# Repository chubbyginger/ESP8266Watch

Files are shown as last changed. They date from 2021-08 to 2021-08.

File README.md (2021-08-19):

# ESP8266Watch
ESP8266 WiFi模组自制可穿戴智能手表

## 功能
1. 使用内置DS1302时钟芯片提供RTC时钟。
2. 鉴于DS1302芯片准确性不高，也可连接WiFi后通过NTP时钟服务器同步时间。
3. 可以使用计时器、定时器等功能。
4. 访问本地文件系统文件或者连接服务器，阅读文本内容。
5. 具有可拓展性（往上面加点简单游戏什么的完全可以）。

## 版本

这个手表有两个版本：

1. dev版本：这个版本用的是一个电位器加一个按钮来操作手表。但是这个设计不方便放进手表，体积会特别大，是明显不合适的。因为不考虑用这个版本做成品，因此此版本没有PCB。

2. 正式版本：这个版本用三个按钮操作手表（上，下，确定），更方便放进手表。这个版本有PCB。

   另外，这个版本取消了DS1302的备用电池，因为其体积实在太大且没什么实际用处。DS1302的布局从SOIC改成了DIP，主要是因为我手残不会焊SOIC。电阻也改成直插式了。
## 制作说明
可以直接用Arduino编译程序下载（如果用ESP8266裸板需要另买USB转串口线一根，把里面TXD和RXD插到裸板的RXD和TXD上），也可以下载已经编译好的bin文件（现在还没准备好）。但是如果需要修改Flash片内内容，则必须用Arduino手动编译。

## 修改片内Flash方法
1. 先参考libconfig文件夹中安装依赖库的说明，安装库和文件系统工具。
2. 在源代码的data文件夹下放置需要的文件。
3. 找到工具->ESP8266 Sketch Data Upload，点击即可上传。

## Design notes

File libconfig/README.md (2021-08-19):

# 配置库
如果家里网不好，直接安装esp8266是巨慢的甚至可能根本装不上，可以用以下方法安装：

1. 从[这里](https://github.com/yangshunhuai/ESP8266Watch/releases/libconfig)下载库配置包
2. 解压缩
3. 运行config.bat
4. 在Arduino的首选项中有一个附加开发板管理器网址，把`https://arduino.esp8266.com/stable/package_esp8266com_index.json`填进去。
5. 在Arduino工具->开发板->开发板管理器中搜索esp8266，点进去，有一个选择版本的下拉菜单，进去选择3.0.2，点右边安装，因为有了预先下载的缓存，安装非常快。

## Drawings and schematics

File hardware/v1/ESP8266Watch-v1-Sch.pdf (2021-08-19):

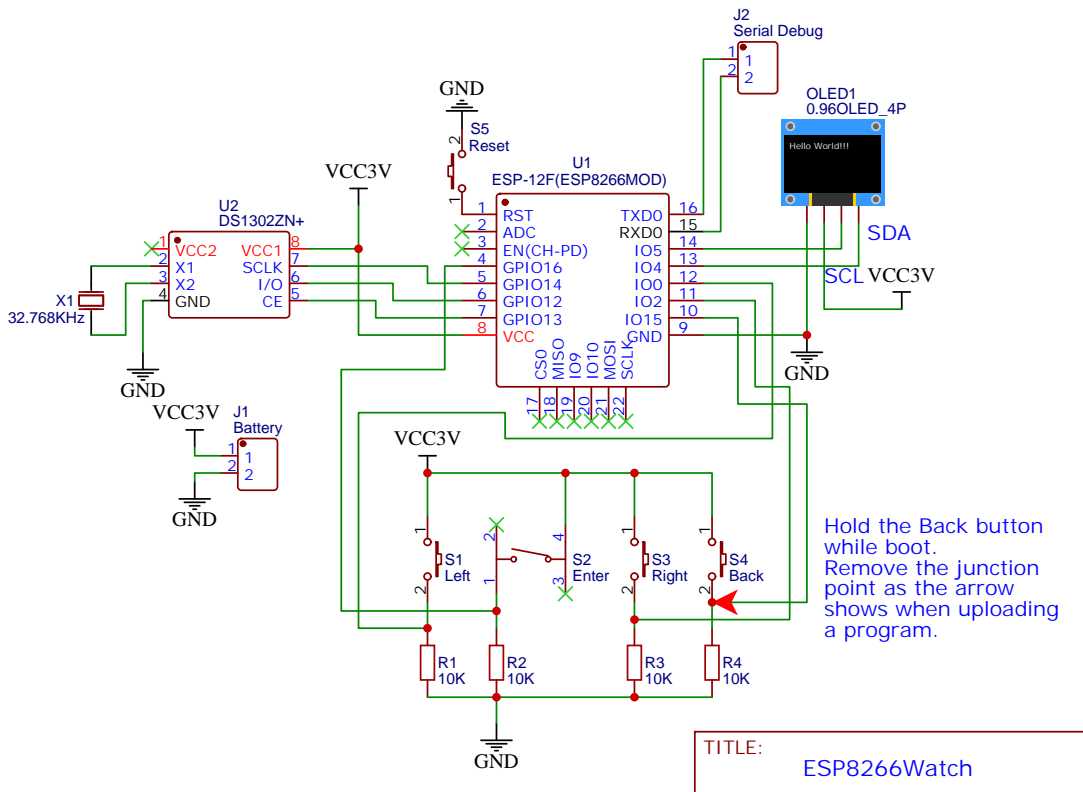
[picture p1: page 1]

Hold the Back button
while boot.
Remove the junction
point as the arrow
shows when uploading
a program.

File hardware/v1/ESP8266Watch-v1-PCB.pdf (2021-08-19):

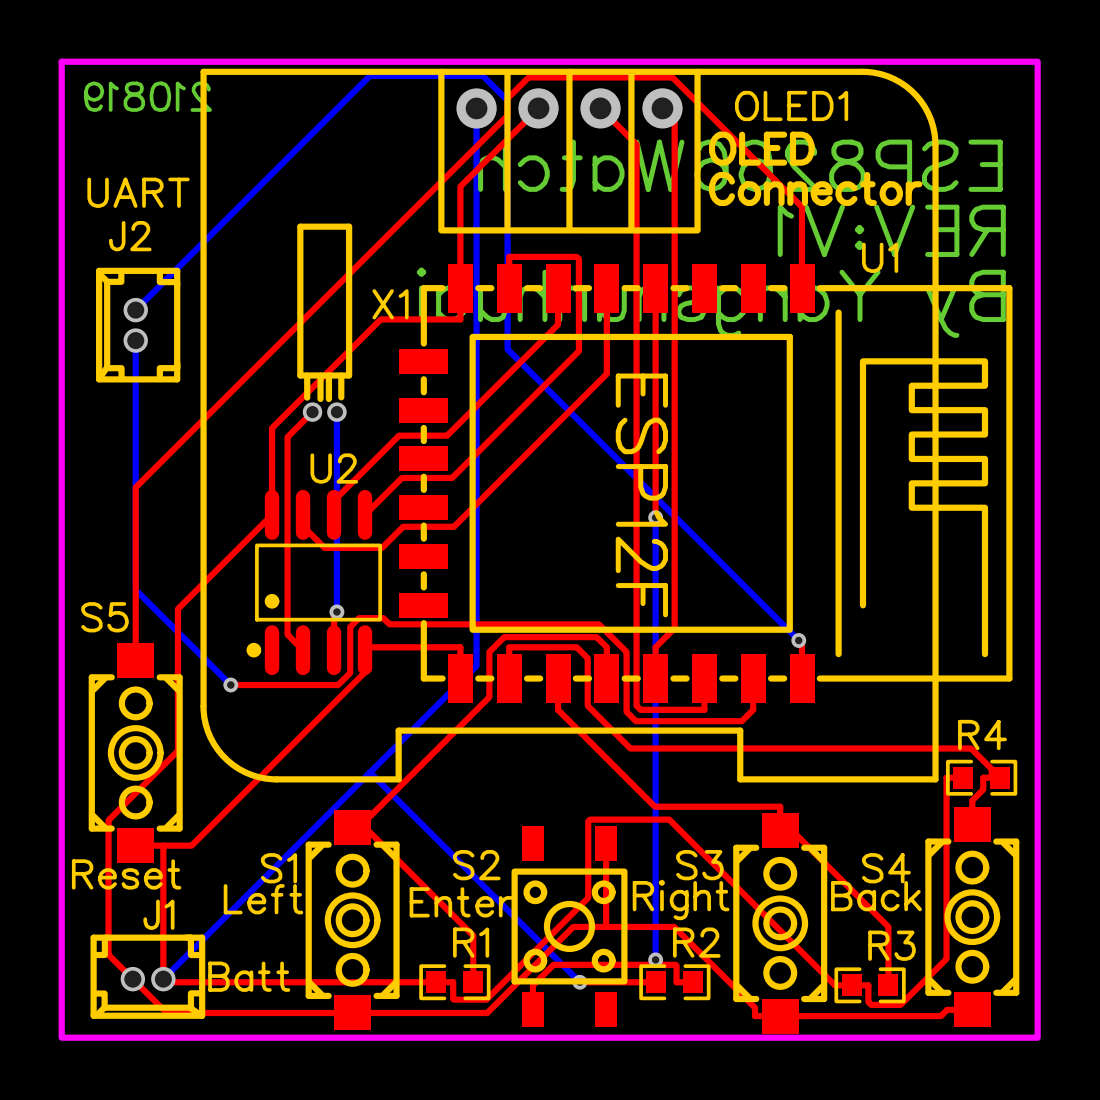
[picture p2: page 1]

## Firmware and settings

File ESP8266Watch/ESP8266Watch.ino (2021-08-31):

/*
   ESP8266Watch REV 1.0
   Connection as the schematics in the hardware folder.

   NOTICE:
   1. When booting the watch, press the BACK key if you are
      using the default pin layout because GPIO 15 cannot be
      high at boot.
   2. When uploading a program, remove the connection between
      GPIO 15 and the BACK key to make sure GPIO 15 floats
      because GPIO 15 must be low during an upload.
*/

#include <DS1302.h>
#include <Wire.h>
#include <U8g2lib.h>
#include <OneButton.h>
#include <ESP8266WiFi.h>
#include <WiFiUdp.h>
#include <NTPClient.h>
#include <EEPROM.h>

// The left button pin:
#define BTNLEFT 0
#define BTNENTER 16
#define BTNRIGHT 2
#define BTNBACK 15
// DS1302 pins:
#define CLK 14
#define DAT 12
#define RST 13
// If your screen has a reset pin, change the reset pin below.
// If your screen doesn't have a reset pin, leave it -1.
#define SCR_WIDTH 128
#define SCR_HEIGHT 64
#define SCR_RESET -1

#define ALIGN_CENTER(a) ((SCR_WIDTH - (u8g2.getUTF8Width(a))) / 2)
#define ALIGN_CENTER_PROCESSED_LENGTH(a) ((SCR_WIDTH - a) / 2)
#define ALIGN_RIGHT(a) (SCR_WIDTH -  u8g2.getUTF8Width(a))
#define ALIGN_LEFT 0
#define countof(a) (sizeof(a) / sizeof(a[0]))

bool btnleftClicked = false;
bool btnenterClicked = false;
bool btnrightClicked = false;
bool btnbackClicked = false;

DS1302 rtc(RST, DAT, CLK);
U8G2_SSD1306_128X64_NONAME_F_HW_I2C u8g2(U8G2_R0, U8X8_PIN_NONE);
OneButton btnleft(BTNLEFT, true);
OneButton btnenter(BTNENTER, true);
OneButton btnright(BTNRIGHT, true);
OneButton btnback(BTNBACK, true);
WiFiUDP udp;
NTPClient timeClient(udp);

void setup() {
  // put your setup code here, to run once:
  Serial.begin(9600);
  Serial.println("ESP8266Watch");
  Serial.println("REV 1.0");
  Serial.println();
  Serial.println("Booting...");
  Serial.println("Configuring RTC...");
  rtc.writeProtect(false);
  rtc.halt(false);
  // Uncomment the two lines below to set the clock.
//  Time t(2021, 8, 25, 22, 31, 50, Time::kWednesday);
//  rtc.time(t);

  Serial.println("Configuring screen...");
  u8g2.begin(BTNENTER, BTNRIGHT, BTNLEFT, U8X8_PIN_NONE);
  u8g2.enableUTF8Print();

  // You may need to configure the internal pullup here.
  Serial.println("Configuring button...");
  btnleft.attachClick(btnleftClickedFunc);
  btnenter.attachClick(btnenterClickedFunc);
  btnright.attachClick(btnrightClickedFunc);
  btnback.attachClick(btnbackClickedFunc);

  Serial.println("Configuring EEPROM...");
  EEPROM.begin(512);
  
  Serial.println("Checking network connection...");
  WiFi.mode(WIFI_STA);
  connectfromconfig();
  Serial.print("Connecting...");
  while (WiFi.status() != WL_CONNECTED) {
    Serial.print(".");
    delay(1000);
  }
  Serial.println("WLAN connected!");
  Serial.print("Current SSID: ");
  Serial.println(WiFi.SSID());
}

void loop() {
  // put your main code here, to run repeatedly:
  btnenter.tick();
  printTime();
  if (btnenterClicked) {
    btnenterClicked = false;
    mainmenu();
  }
}

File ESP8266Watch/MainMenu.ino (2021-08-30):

char *mainmenuitems =
  "<-- Back\n"
  "File Manager\n"
  "Settings";

void mainmenu() {
  int selection = 0;
  while (true) {
    selection = u8g2.userInterfaceSelectionList("Main Menu", selection, mainmenuitems);
    if (selection == 1) {
      return;
    } else if (selection == 3) {
      settingsmenu();
    } else {
      u8g2.userInterfaceMessage("Developing", "Go back", "", " OK ");
    }
    yield();
  }
}

int selectionmenu(String title, char *items[], int glyphs[]) {
  unsigned int selection = 0;
  bool first = true;
  bool last = false;
  char *currenttext = items[selection];
  while (!btnenterClicked) {
    u8g2.clearBuffer();
    u8g2.setFont(u8g2_font_ncenB10_tr);
    u8g2.drawStr(ALIGN_CENTER(title.c_str()), 12, title.c_str());
    u8g2.drawHLine(0, 14, SCR_WIDTH);
    u8g2.setFont(u8g2_font_open_iconic_all_4x_t);
    u8g2.drawGlyph(ALIGN_CENTER_PROCESSED_LENGTH(32), 50, glyphs[selection]);
//    if (first) {
//      u8g2.drawTriangle(10, 30, 10, 34, 5, 32);
//    } else if (last) {
//      u8g2.drawTriangle(118, 30, 118, 34, 123, 32);
//    } else {
//      u8g2.drawTriangle(10, 30, 10, 34, 5, 32);
//      u8g2.drawTriangle(118, 30, 118, 34, 123, 32);
//    }
    u8g2.drawStr(ALIGN_CENTER(currenttext), 63, currenttext);
    u8g2.sendBuffer();
    btnleft.tick();
    btnright.tick();
    btnenter.tick();
    btnback.tick();
    if (btnleftClicked && (selection != 0)) {
      btnleftClicked = false;
      selection--;
    }
    if (btnrightClicked && (selection != countof(items))) {
      btnrightClicked = false;
      selection++;
    }
    if (btnbackClicked) {
      btnbackClicked = false;
      return -1;
    }
    yield();
  }
  btnenterClicked = false;
  return selection;
}

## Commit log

2021-07-22 Sketch: Draw some sketches
    [ESP8266WatchFritzing.fzz]
2021-08-14 Sketch: Change pdsprj to schdoc
    [ESP8266Watch.schdoc, ESP8266WatchFritzing.fzz]
2021-08-16 hardware: Add version dev
    [ESP8266Watch-dev-Sch.schdoc, ESP8266WatchFritzing.fzz]
2021-08-17 hardware: Update schematic and PCB
    [ESP8266Watch-v1-PCB.pcbdoc, ESP8266Watch-v1-Sch.schdoc]
2021-08-18 hardware: Remove dev version
    [ESP8266Watch-dev-Sch.schdoc]
2021-08-19 hardware: Update hardware
    [ESP8266Watch-v1-PCB.pcbdoc, ESP8266Watch-v1-Sch.schdoc]
